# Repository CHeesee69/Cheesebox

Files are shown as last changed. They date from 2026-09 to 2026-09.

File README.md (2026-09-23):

# Cheesebox
The cheesebox is a small emulation device that uses a CM5 board. It will have the power to emulate 5th-gen and select 6th- and 7th-gen hardware. I plan for it to be kind of flat so I can make a screen, battery, and controller add-on down the line to make it portable. Why is it called "The Cheesebox"? Because I like cheese. Duh.

# Features

Cool Design

Power Light

Two USB-C Ports

Two USB-A 3.0 Ports

Two USB-A 2.0 Ports

Magjack Ethernet Port

3.5 mm Headphone Jack

Micro SD Card Slot

2242 M.2 SSD or NVMe Slot (3rd Gen)

HDMI Output





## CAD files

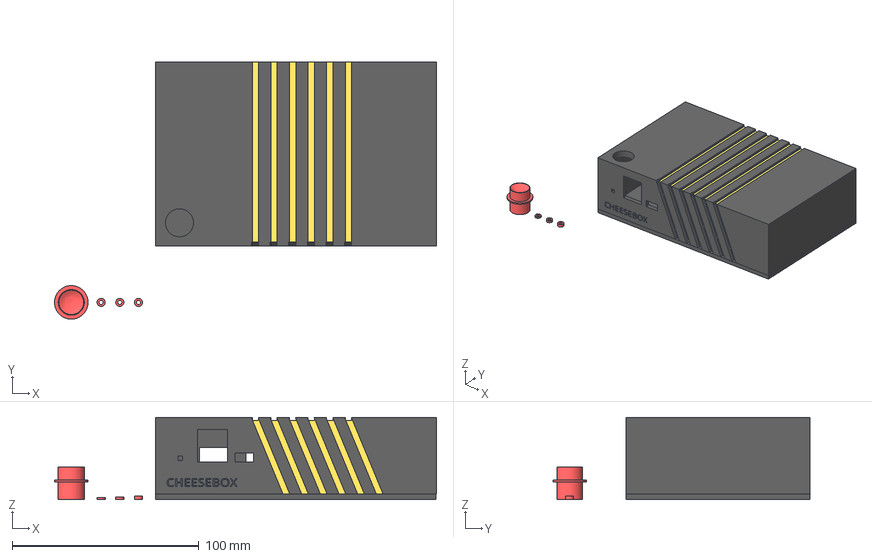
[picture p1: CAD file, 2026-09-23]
CAD/Assembled_model.step
204.7 x 137.9 x 44.0 mm

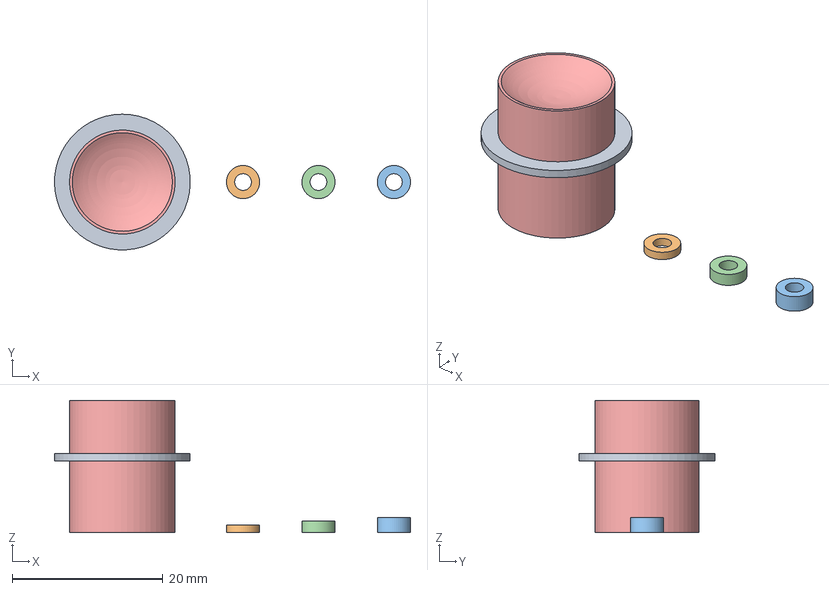
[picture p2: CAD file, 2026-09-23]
Production/Button_and_standoffs.step
47.2 x 18.0 x 17.5 mm

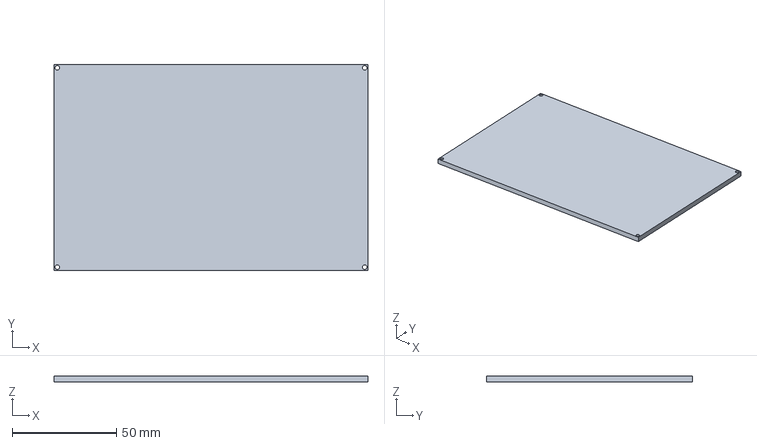
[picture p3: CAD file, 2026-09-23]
Production/Bottom.step
150.5 x 98.7 x 3.00 mm

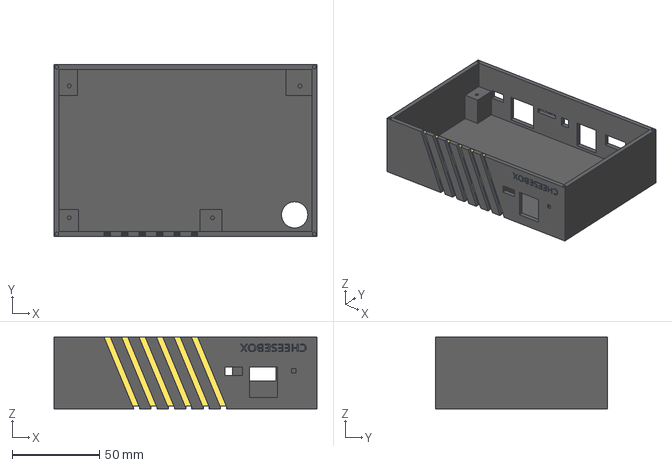
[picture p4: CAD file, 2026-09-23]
Production/Top.step
150.5 x 98.7 x 41.0 mm

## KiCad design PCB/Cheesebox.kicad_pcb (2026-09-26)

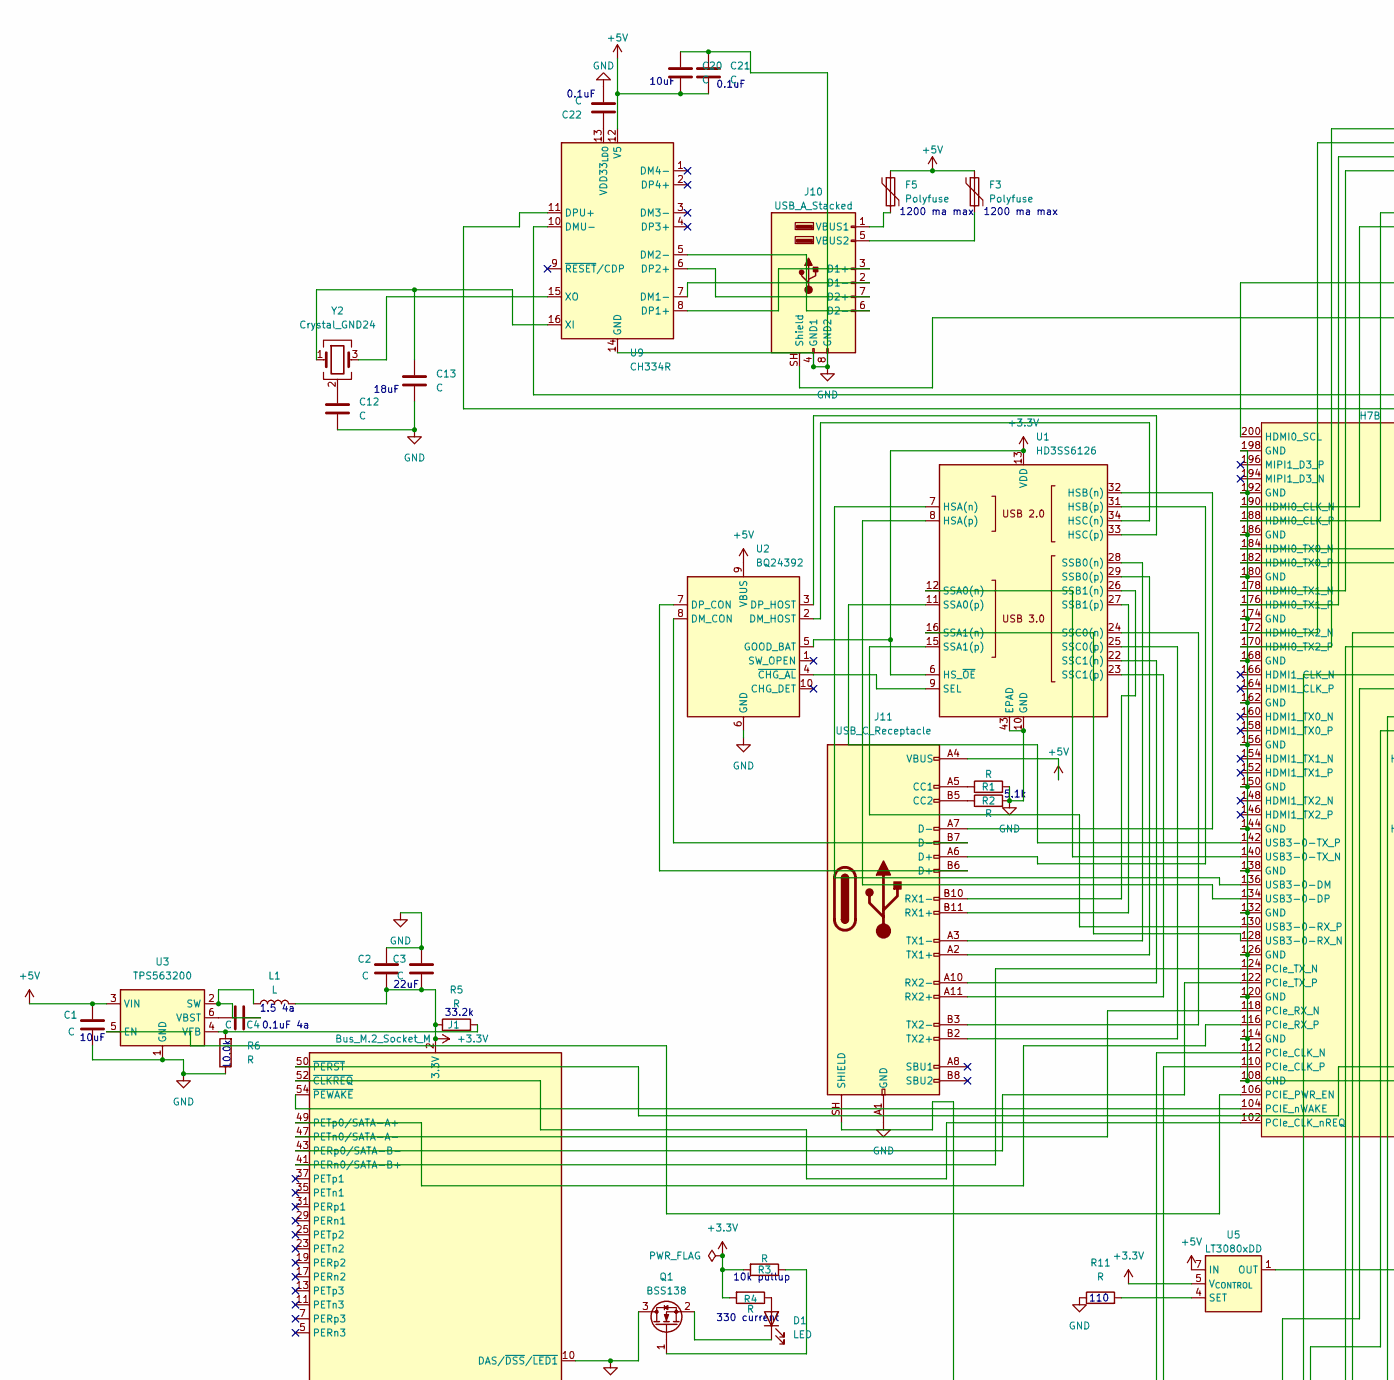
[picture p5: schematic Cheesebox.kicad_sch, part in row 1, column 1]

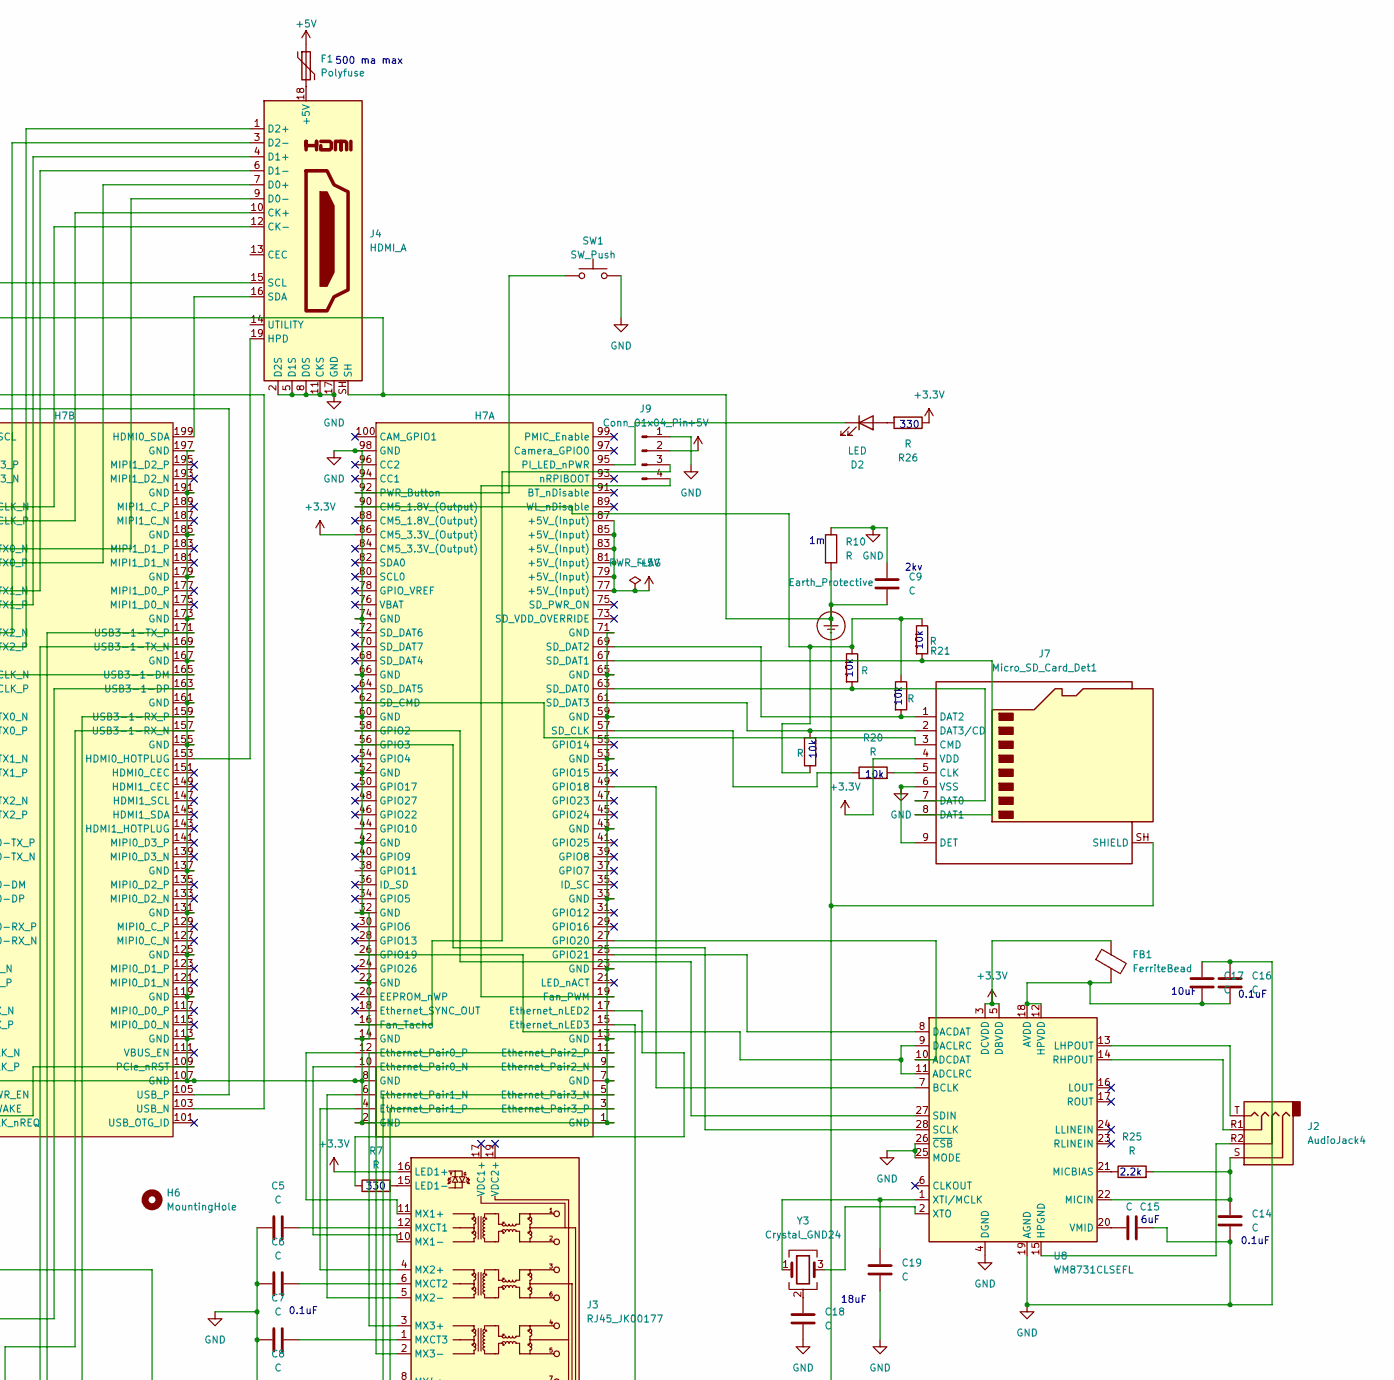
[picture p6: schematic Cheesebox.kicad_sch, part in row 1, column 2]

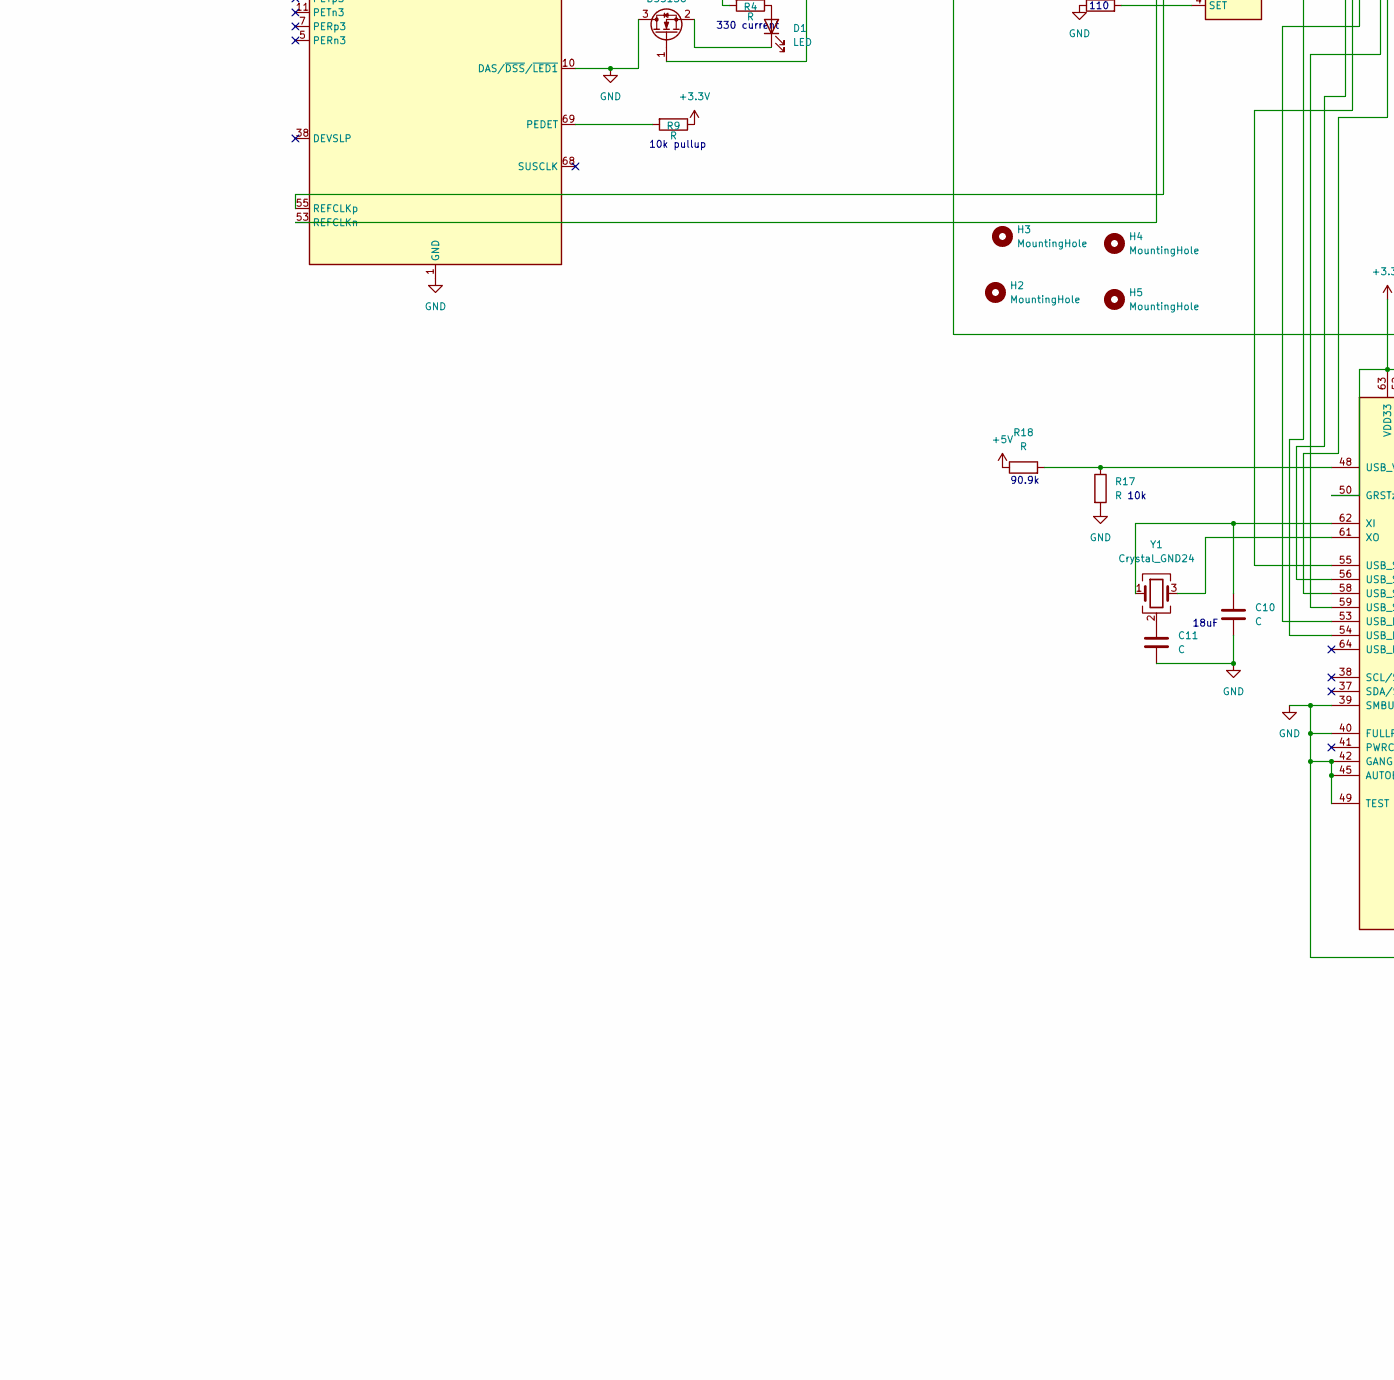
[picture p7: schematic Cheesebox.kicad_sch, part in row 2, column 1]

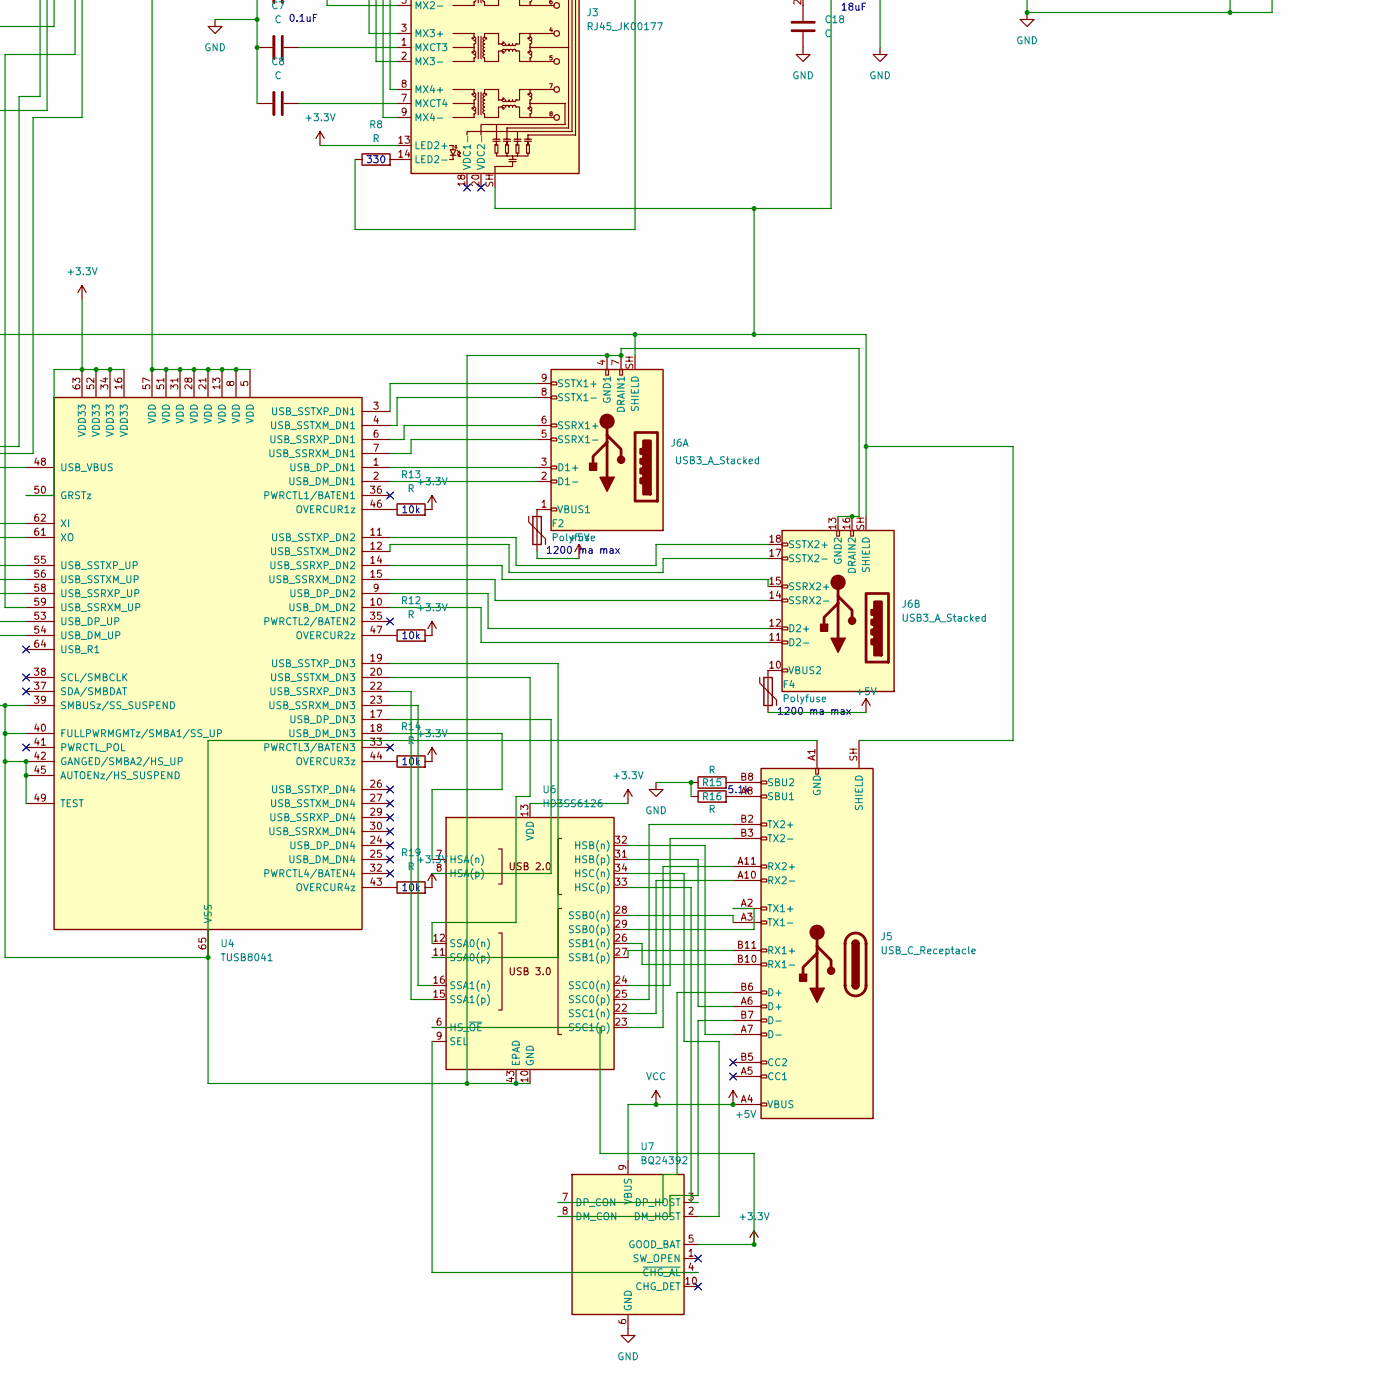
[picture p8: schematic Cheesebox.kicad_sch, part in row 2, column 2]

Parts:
C1, C2, C3, C10, C11, C12, C13, C15, C17, C18, C19, C20: C; C_0805_2012Metric_Pad1.18x1.45mm_HandSolder
C4, C5, C6, C7, C8, C9, C14, C16, C21, C22: C; C_0603_1608Metric_Pad1.08x0.95mm_HandSolder
D1, D2: LED; LED_0603_1608Metric_Pad1.05x0.95mm_HandSolder
F1: Polyfuse; Fuse_1206_3216Metric_Pad1.42x1.75mm_HandSolder
F2, F3, F4, F5: Polyfuse; Fuse_1210_3225Metric_Pad1.42x2.65mm_HandSolder
FB1: FerriteBead; L_0805_2012Metric_Pad1.05x1.20mm_HandSolder
H2, H3, H4, H5: MountingHole; MountingHole_2.5mm
H6: MountingHole; MountingHole_2.2mm_M2
H7: RaspberryPi-CM5-Carrier-Short-NPTH-Silk
J1: Bus_M.2_Socket_M; CONN67_2199230_TEC
J2: AudioJack4; Jack_3.5mm_CUI_SJ-3524-SMT_Horizontal
J3: RJ45_JK00177; RJ45_Pulse_JK00177NL_Horizontal
J4: HDMI_A; HDMI_A_Amphenol_10029449-x01xLF_Horizontal
J5, J11: USB_C_Receptacle; USB_C_Receptacle_Amphenol_12401548E4-2A_CircularHoles
J6: USB3_A_Stacked; USB3_A_Molex_48406-0001_Horizontal_Stacked
J7: Micro_SD_Card_Det1; microSD_HC_Hirose_DM3AT-SF-PEJM5
J9: Conn_01x04_Pin; FanPinHeader_1x04_P2.54mm_Vertical
J10: USB_A_Stacked; USB_A_Wuerth_61400826021_Horizontal_Stacked
L1: L; L_Coilcraft_XAL4040-XXX
Q1: BSS138; SOT-23
R1, R2, R3, R4, R7, R8, R9, R10, R11, R12, R13, R14, R15, R16, R19, R20, R21, R22, R23, R24, R25, R26: R; R_0805_2012Metric_Pad1.20x1.40mm_HandSolder
R5, R6, R17, R18: R; R_1206_3216Metric_Pad1.30x1.75mm_HandSolder
SW1: SW_Push; SW_PUSH_6mm_H5mm
U1, U6: HD3SS6126; WQFN-42-1EP_3.5x9mm_P0.5mm_EP2.05x7.55mm_ThermalVias
U2, U7: BQ24392; Texas_R-PUQFN-N10
U3: TPS563200; SOT-23-6
U4: TUSB8041; QFN-64-1EP_9x9mm_P0.5mm_EP6x6mm_ThermalVias
U5: LT3080xDD; DFN-8-1EP_3x3mm_P0.5mm_EP1.66x2.38mm
U8: WM8731CLSEFL; QFN-28-1EP_5x5mm_P0.5mm_EP3.35x3.35mm
U9: CH334R; QSOP-16_3.9x4.9mm_P0.635mm
Y1, Y2, Y3: Crystal_GND24; Resonator-3Pin_W6.0mm_H3.0mm

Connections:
+3.3V: C2.2, C3.2, FB1.1, H7.86 (CM5_3.3V_(Output)), J1.2 (3.3V), J1.4 (3.3V), J1.12 (3.3V), J1.14 (3.3V), J1.16 (3.3V), J1.18 (3.3V), J1.70 (3.3V), J1.72 (3.3V), J1.74 (3.3V), J3.13 (LED2+), J3.16 (LED1+), J7.4 (VDD), L1.2, R3.2, R4.2, R5.1, R9.1, R12.2, R13.2, R14.2, R19.2, R26.1, U1.6 (HS_~OE), U1.13 (VDD), U1.20 (VDD), U1.30 (VDD), U2.5 (GOOD_BAT), U4.16 (VDD33), U4.34 (VDD33), U4.50 (GRSTz), U4.52 (VDD33), U4.63 (VDD33), U5.5 (V_{CONTROL}), U6.6 (HS_~OE), U6.13 (VDD), U6.20 (VDD), U6.30 (VDD), U7.5 (GOOD_BAT), U8.3 (DCVDD), U8.5 (DBVDD)
+5V: C1.1, C20.1, C21.2, F1.1, F2.2, F3.1, F4.2, F5.1, H7.77 (+5V_(Input)), H7.79 (+5V_(Input)), H7.81 (+5V_(Input)), H7.83 (+5V_(Input)), H7.85 (+5V_(Input)), H7.87 (+5V_(Input)), J5.A4 (VBUS), J5.A9 (VBUS), J5.B4 (VBUS), J5.B9 (VBUS), J9.2, J11.A4 (VBUS), J11.A9 (VBUS), J11.B4 (VBUS), J11.B9 (VBUS), R18.1, U2.9 (VBUS), U3.3 (VIN), U5.7 (IN), U5.8 (IN), U7.9 (VBUS), U9.12 (V5)
Earth_Protective: C9.2, J3.SH, J4.SH, J5.SH (SHIELD), J6.SH (SHIELD), J7.SH (SHIELD), J10.SH (Shield), J11.SH (SHIELD), R10.2
GND: C1.2, C2.1, C3.1, C5.1, C6.1, C7.1, C8.1, C9.1, C10.1, C11.1, C12.1, C13.1, C14.2, C15.1, C16.1, C17.2, C18.1, C19.1, C20.2, C21.1, C22.2, H7.1 (GND), H7.2 (GND), H7.7 (GND), H7.8 (GND), H7.13 (GND), H7.14 (GND), H7.22 (GND), H7.23 (GND), H7.32 (GND), H7.33 (GND), H7.42 (GND), H7.43 (GND), H7.52 (GND), H7.53 (GND), H7.59 (GND), H7.60 (GND), H7.65 (GND), H7.66 (GND), H7.71 (GND), H7.74 (GND), H7.98 (GND), H7.107 (GND), H7.108 (GND), H7.113 (GND), H7.114 (GND), H7.119 (GND), H7.120 (GND), H7.125 (GND), H7.126 (GND), H7.131 (GND), H7.132 (GND), H7.137 (GND), H7.138 (GND), H7.144 (GND), H7.150 (GND), H7.155 (GND), H7.156 (GND), H7.161 (GND), H7.162 (GND), H7.167 (GND), H7.168 (GND), H7.173 (GND), H7.174 (GND), H7.179 (GND), H7.180 (GND), H7.185 (GND), H7.186 (GND), H7.191 (GND), H7.192 (GND), H7.197 (GND), H7.198 (GND), J1.1 (GND), J1.3 (GND), J1.9 (GND), J1.10 (DAS/~DSS/~LED1), J1.15 (GND), J1.21 (GND), J1.27 (GND), J1.33 (GND), J1.39 (GND), J1.45 (GND), J1.51 (GND), J1.57 (GND), J1.71 (GND), J1.73 (GND), J1.75 (GND), J4.2 (D2S), J4.5 (D1S), J4.8 (D0S), J4.11 (CKS), J4.17 (GND), J5.A1 (GND), J5.A12 (GND), J5.B1 (GND), J5.B12 (GND), J6.4 (GND1), J6.7 (DRAIN1), J6.13 (GND2), J6.16 (DRAIN2), J7.6 (VSS), J7.9 (DET), J9.1, J10.4 (GND1), J10.8 (GND2), J11.A1 (GND), J11.A12 (GND), J11.B1 (GND), J11.B12 (GND), Q1.3 (D), R1.2, R2.2, R6.1, R10.1, R11.1, R15.1, R16.1, R17.2, SW1.2, U1.10 (GND), U1.14 (GND), U1.17 (GND), U1.19 (GND), U1.21 (GND), U1.43 (EPAD), U2.6 (GND), U3.1 (GND), U4.39 (SMBUSz/SS_SUSPEND), U4.40 (FULLPWRMGMTz/SMBA1/SS_UP), U4.42 (GANGED/SMBA2/HS_UP), U4.45 (AUTOENz/HS_SUSPEND), U4.49 (TEST), U4.65 (VSS), U6.10 (GND), U6.14 (GND), U6.17 (GND), U6.19 (GND), U6.21 (GND), U6.43 (EPAD), U7.6 (GND), U8.4 (DGND), U8.19 (AGND), U8.25 (MODE), U8.26 (~CSB), U8.29 (AGND), U9.14 (GND)
unnamed: C11.2, Y1.2 (G), Y1.4 (G)
unnamed: C12.2, Y2.2 (G), Y2.4 (G)
unnamed: C18.2, Y3.2 (G), Y3.4 (G)
unnamed: D1.2 (A), R4.1
unnamed: D1.1 (K), Q1.2 (S)
unnamed: D2.2 (A), R26.2
unnamed: D2.1 (K), H7.95 (PI_LED_nPWR)
unnamed: H7.90 (CM5_1.8V_(Output)), R21.1, R22.1, R23.1, R24.1
unnamed: H7.10 (Ethernet_Pair0_N), J3.10 (MX1-)
unnamed: H7.12 (Ethernet_Pair0_P), J3.11 (MX1+)
unnamed: H7.6 (Ethernet_Pair1_N), J3.5 (MX2-)
unnamed: H7.4 (Ethernet_Pair1_P), J3.4 (MX2+)
unnamed: H7.9 (Ethernet_Pair2_N), J3.2 (MX3-)
unnamed: H7.11 (Ethernet_Pair2_P), J3.3 (MX3+)
unnamed: H7.5 (Ethernet_Pair3_N), J3.9 (MX4-)
unnamed: H7.3 (Ethernet_Pair3_P), J3.8 (MX4+)
unnamed: H7.17 (Ethernet_nLED2), R7.1
unnamed: H7.15 (Ethernet_nLED3), R8.1
unnamed: H7.19 (Fan_PWM), J9.4
unnamed: H7.16 (Fan_Tacho), J9.3
unnamed: H7.58 (GPIO2), U8.27 (SDIN)
unnamed: H7.56 (GPIO3), U8.28 (SCLK)
unnamed: H7.49 (GPIO18), U8.7 (BCLK)
unnamed: H7.26 (GPIO19), U8.9 (DACLRC), U8.11 (ADCLRC)
unnamed: H7.27 (GPIO20), U8.10 (ADCDAT)
unnamed: H7.25 (GPIO21), U8.8 (DACDAT)
unnamed: H7.92 (PWR_Button), SW1.1
unnamed: H7.57 (SD_CLK), R20.1
unnamed: H7.62 (SD_CMD), J7.3 (CMD)
unnamed: H7.63 (SD_DAT0), J7.7 (DAT0), R22.2
unnamed: H7.67 (SD_DAT1), J7.8 (DAT1), R21.2
unnamed: H7.69 (SD_DAT2), J7.1 (DAT2), R23.2
unnamed: H7.61 (SD_DAT3), J7.2 (DAT3/CD), R24.2
unnamed: H7.190 (HDMI0_CLK_N), J4.12 (CK-)
unnamed: H7.188 (HDMI0_CLK_P), J4.10 (CK+)
unnamed: H7.153 (HDMI0_HOTPLUG), J4.19 (HPD)
unnamed: H7.200 (HDMI0_SCL), J4.15 (SCL)
unnamed: H7.199 (HDMI0_SDA), J4.16 (SDA)
unnamed: H7.184 (HDMI0_TX0_N), J4.9 (D0-)
unnamed: H7.182 (HDMI0_TX0_P), J4.7 (D0+)
unnamed: H7.178 (HDMI0_TX1_N), J4.6 (D1-)
unnamed: H7.176 (HDMI0_TX1_P), J4.4 (D1+)
unnamed: H7.172 (HDMI0_TX2_N), J4.3 (D2-)
unnamed: H7.170 (HDMI0_TX2_P), J4.1 (D2+)
unnamed: H7.106 (PCIE_PWR_EN), U3.5 (EN)
unnamed: H7.104 (PCIE_nWAKE), J1.54 (~PEWAKE)
unnamed: H7.112 (PCIe_CLK_N), J1.53 (REFCLKn)
unnamed: H7.110 (PCIe_CLK_P), J1.55 (REFCLKp)
unnamed: H7.102 (PCIe_CLK_nREQ), J1.52 (~CLKREQ)
unnamed: H7.118 (PCIe_RX_N), J1.47 (PETn0/SATA-A-)
unnamed: H7.116 (PCIe_RX_P), J1.49 (PETp0/SATA-A+)
unnamed: H7.124 (PCIe_TX_N), J1.41 (PERn0/SATA-B+)
unnamed: H7.122 (PCIe_TX_P), J1.43 (PERp0/SATA-B-)
unnamed: H7.109 (PCIe_nRST), J1.50 (~PERST)
unnamed: H7.136 (USB3-0-DM), U1.7 (HSA(n))
unnamed: H7.134 (USB3-0-DP), U1.8 (HSA(p))
unnamed: H7.128 (USB3-0-RX_N), U1.16 (SSA1(n))
unnamed: H7.130 (USB3-0-RX_P), U1.15 (SSA1(p))
unnamed: H7.140 (USB3-0-TX_N), U1.12 (SSA0(n))
unnamed: H7.142 (USB3-0-TX_P), U1.11 (SSA0(p))
unnamed: H7.165 (USB3-1-DM), U4.54 (USB_DM_UP)
unnamed: H7.163 (USB3-1-DP), U4.53 (USB_DP_UP)
unnamed: H7.157 (USB3-1-RX_N), U4.59 (USB_SSRXM_UP)
unnamed: H7.159 (USB3-1-RX_P), U4.58 (USB_SSRXP_UP)
unnamed: H7.169 (USB3-1-TX_N), U4.56 (USB_SSTXM_UP)
unnamed: H7.171 (USB3-1-TX_P), U4.55 (USB_SSTXP_UP)
unnamed: H7.103 (USB_N), U9.10 (DMU-)
unnamed: H7.105 (USB_P), U9.11 (DPU+)
unnamed: J1.69 (PEDET), R9.2
unnamed: J3.15 (LED1-), R7.2
unnamed: J3.14 (LED2-), R8.2
unnamed: C5.2, J3.12 (MXCT1)
unnamed: C6.2, J3.6 (MXCT2)
unnamed: C7.2, J3.1 (MXCT3)
unnamed: C8.2, J3.7 (MXCT4)
unnamed: F1.2, J4.18 (+5V)
unnamed: J5.B11 (RX1+), U6.27 (SSB1(p))
unnamed: J5.B10 (RX1-), U6.26 (SSB1(n))
unnamed: J5.A11 (RX2+), U6.23 (SSC1(p))
unnamed: J5.A10 (RX2-), U6.22 (SSC1(n))
unnamed: J5.A8 (SBU1), R16.2
unnamed: J5.B8 (SBU2), R15.2
unnamed: J5.A2 (TX1+), U6.29 (SSB0(p))
unnamed: J5.A3 (TX1-), U6.28 (SSB0(n))
unnamed: J5.B2 (TX2+), U6.25 (SSC0(p))
unnamed: J5.B3 (TX2-), U6.24 (SSC0(n))
unnamed: J6.3 (D1+), U4.1 (USB_DP_DN1)
unnamed: J6.2 (D1-), U4.2 (USB_DM_DN1)
unnamed: J6.6 (SSRX1+), U4.6 (USB_SSRXP_DN1)
unnamed: J6.5 (SSRX1-), U4.7 (USB_SSRXM_DN1)
unnamed: J6.9 (SSTX1+), U4.3 (USB_SSTXP_DN1)
unnamed: J6.8 (SSTX1-), U4.4 (USB_SSTXM_DN1)
unnamed: F2.1, J6.1 (VBUS1)
unnamed: J6.12 (D2+), U4.9 (USB_DP_DN2)
unnamed: J6.11 (D2-), U4.10 (USB_DM_DN2)
unnamed: J6.15 (SSRX2+), U4.14 (USB_SSRXP_DN2)
unnamed: J6.14 (SSRX2-), U4.15 (USB_SSRXM_DN2)
unnamed: J6.18 (SSTX2+), U4.11 (USB_SSTXP_DN2)
unnamed: J6.17 (SSTX2-), U4.12 (USB_SSTXM_DN2)
unnamed: F4.1, J6.10 (VBUS2)
unnamed: J7.5 (CLK), R20.2
unnamed: J10.3 (D1+), U9.8 (DP1+)
unnamed: J10.2 (D1-), U9.7 (DM1-)
unnamed: J10.7 (D2+), U9.6 (DP2+)
unnamed: J10.6 (D2-), U9.5 (DM2-)
unnamed: F5.2, J10.1 (VBUS1)
unnamed: F3.2, J10.5 (VBUS2)
unnamed: J11.A5 (CC1), R1.1
unnamed: J11.B5 (CC2), R2.1
unnamed: J11.B11 (RX1+), U1.27 (SSB1(p))
unnamed: J11.B10 (RX1-), U1.26 (SSB1(n))
unnamed: J11.A11 (RX2+), U1.23 (SSC1(p))
unnamed: J11.A10 (RX2-), U1.22 (SSC1(n))
unnamed: J11.A2 (TX1+), U1.29 (SSB0(p))
unnamed: J11.A3 (TX1-), U1.28 (SSB0(n))
unnamed: J11.B2 (TX2+), U1.25 (SSC0(p))
unnamed: J11.B3 (TX2-), U1.24 (SSC0(n))
unnamed: Q1.1 (G), R3.1
unnamed: J11.A7 (D-), U1.32 (HSB(n))
unnamed: J11.A6 (D+), U1.31 (HSB(p))
unnamed: U1.34 (HSC(n)), U2.2 (DM_HOST)
unnamed: U1.33 (HSC(p)), U2.3 (DP_HOST)
unnamed: U1.9 (SEL), U2.4 (~CHG_AL)
unnamed: J11.B7 (D-), U2.8 (DM_CON)
unnamed: J11.B6 (D+), U2.7 (DP_CON)
unnamed: C4.2, L1.1, U3.2 (SW)
unnamed: C4.1, U3.6 (VBST)
unnamed: R5.2, R6.2, U3.4 (VFB)
unnamed: R13.1, U4.46 (OVERCUR1z)
unnamed: R12.1, U4.47 (OVERCUR2z)
unnamed: R14.1, U4.44 (OVERCUR3z)
unnamed: R19.1, U4.43 (OVERCUR4z)
unnamed: U4.18 (USB_DM_DN3), U6.7 (HSA(n))
unnamed: U4.17 (USB_DP_DN3), U6.8 (HSA(p))
unnamed: U4.23 (USB_SSRXM_DN3), U6.16 (SSA1(n))
unnamed: U4.22 (USB_SSRXP_DN3), U6.15 (SSA1(p))
unnamed: U4.20 (USB_SSTXM_DN3), U6.12 (SSA0(n))
unnamed: U4.19 (USB_SSTXP_DN3), U6.11 (SSA0(p))
unnamed: R17.1, R18.2, U4.48 (USB_VBUS)
unnamed: U4.5 (VDD), U4.8 (VDD), U4.13 (VDD), U4.21 (VDD), U4.28 (VDD), U4.31 (VDD), U4.51 (VDD), U4.57 (VDD), U5.1 (OUT), U5.2 (OUT), U5.3 (OUT), U5.9 (OUT)
unnamed: C10.2, U4.62 (XI), Y1.1
unnamed: U4.61 (XO), Y1.3
unnamed: R11.2, U5.4 (SET)
unnamed: J5.A7 (D-), U6.32 (HSB(n))
unnamed: J5.A6 (D+), U6.31 (HSB(p))
unnamed: U6.34 (HSC(n)), U7.2 (DM_HOST)
unnamed: U6.33 (HSC(p)), U7.3 (DP_HOST)
unnamed: U6.9 (SEL), U7.4 (~CHG_AL)
unnamed: J5.B7 (D-), U7.8 (DM_CON)
unnamed: J5.B6 (D+), U7.7 (DP_CON)
unnamed: C16.2, C17.1, FB1.2, U8.12 (HPVDD), U8.18 (AVDD)
unnamed: J2.R2, U8.15 (HPGND)
unnamed: J2.T, U8.13 (LHPOUT)
unnamed: R25.1, U8.21 (MICBIAS)
unnamed: C14.1, J2.S, R25.2, U8.22 (MICIN)
unnamed: J2.R1, U8.14 (RHPOUT)
unnamed: C15.2, U8.20 (VMID)
unnamed: C19.2, U8.1 (XTI/MCLK), Y3.1
unnamed: U8.2 (XTO), Y3.3
unnamed: C22.1, U9.13 (VDD33_{LDO})
unnamed: C13.2, U9.16 (XI), Y2.1
unnamed: U9.15 (XO), Y2.3

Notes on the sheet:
10k
2kv
10uF
22uF
330
10k
1200 ma max
18uF
5.1k
33.2k
90.9k
10.0k
0.1uF
1.5 4a
330 current
110
10k pullup
6uF
0.1uF 4a
2.2k
500 ma max

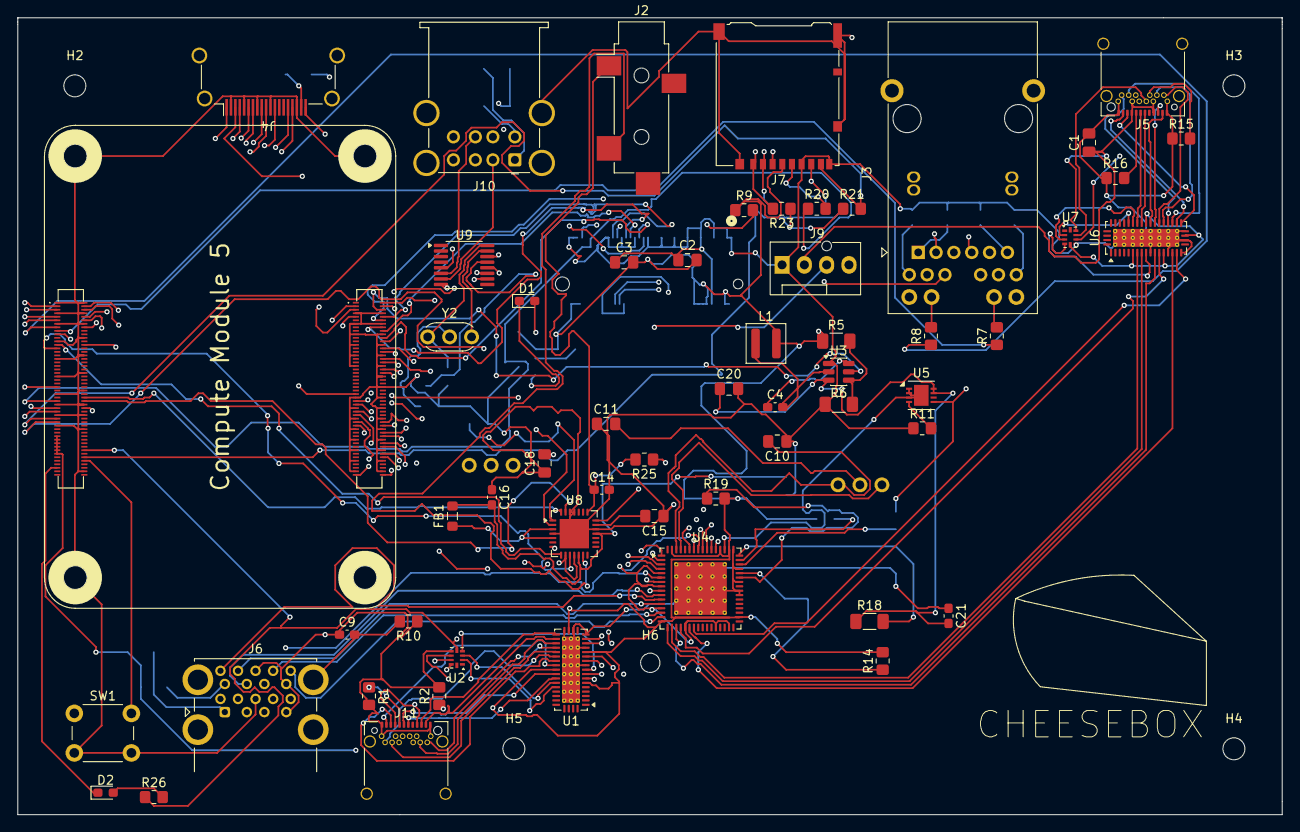
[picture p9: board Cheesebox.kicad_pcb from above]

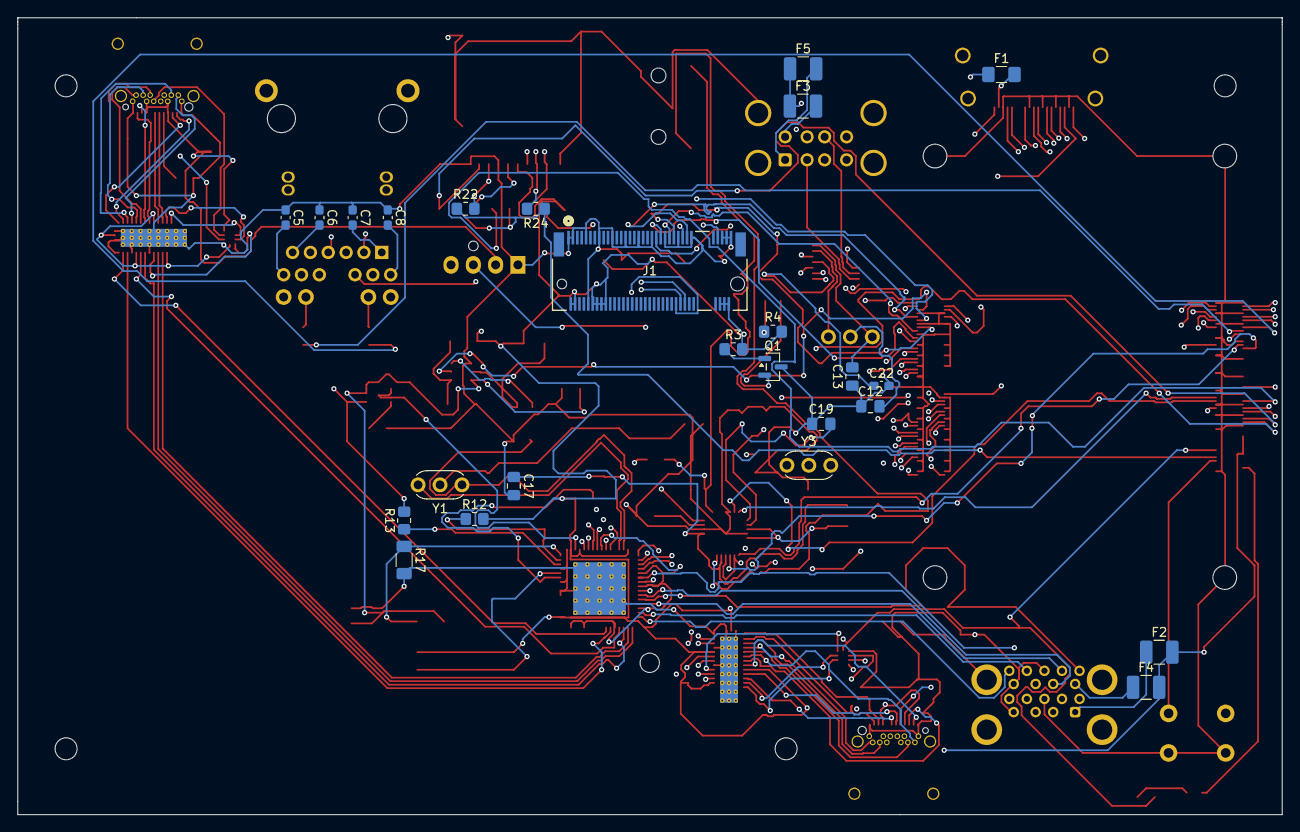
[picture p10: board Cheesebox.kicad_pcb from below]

Board: 6 copper layers, 144.0 x 90.8 mm, 87 parts (25 on the bottom side), 164 nets.

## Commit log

2026-09-19 Adding CAD files
    [cheesebox.kicad_pcb, cheesebox.kicad_sch]
2026-09-23 Updated CAD files
    [Cheesebox.kicad_pcb, cheesebox.kicad_sch]
2026-09-23 Updated PCB
    [Cheesebox.kicad_pcb, cheesebox.kicad_sch]
2026-09-26 Updated PCB folder
    [Cheesebox.kicad_pcb, Cheesebox.kicad_sch]
